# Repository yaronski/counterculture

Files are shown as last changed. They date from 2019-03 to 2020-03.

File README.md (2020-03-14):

# counterculture
Someone:
```
»Do you speak Chinese?«
```
You:
```
»No, but I can count to 10 in Chinese!«
```

Being able to quantify is essential while learning a new language. Also, it's cool.\
Combining visual and auditory sensory input at the push of an arcade style button, learning to count from 0 to 10 in Korean, Japanese, Chinese, Hindi, German and Polish is now easy and fun.

_counterculture_ is a device I invented & built to encourage starting to learn a new language and have some fun with electronics. A project realized during my stay at the National Taiwan University of Technology (NTUT) in Taipei.\
Digital Fabrication class by Prof. N. Tai, 2018/19.

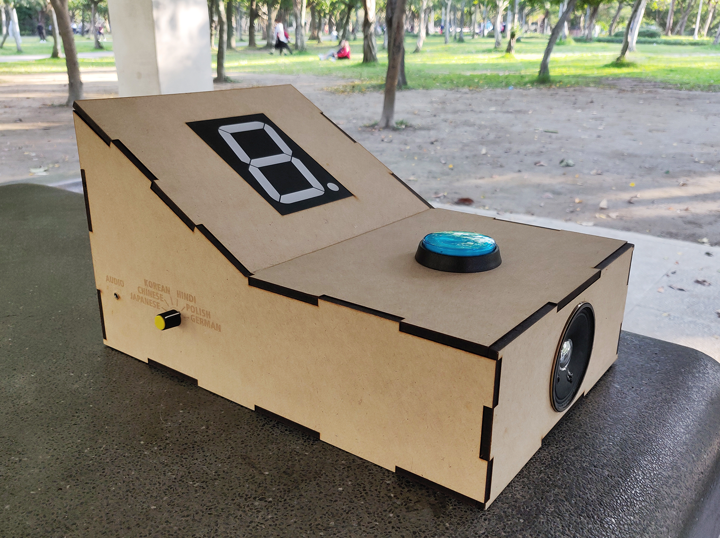
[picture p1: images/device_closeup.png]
device


### video
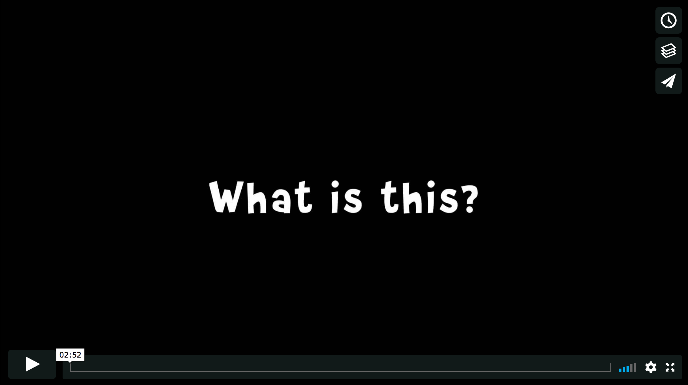
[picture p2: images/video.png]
counterculture (https://vimeo.com/322227320 "counterculture - click to watch!")


### highly complicated circuit diagram
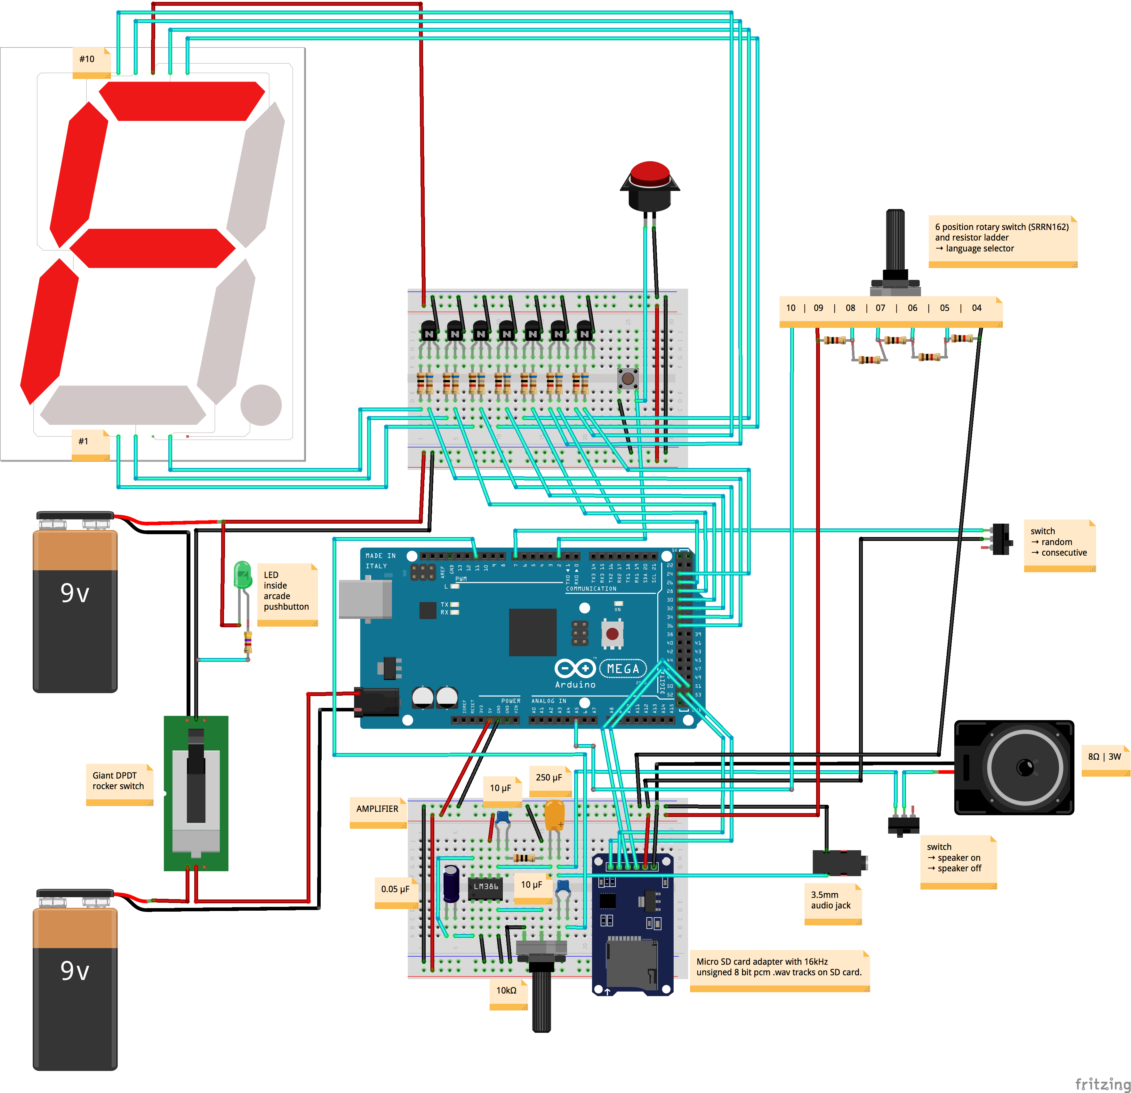
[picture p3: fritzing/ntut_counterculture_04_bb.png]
fritzing


### construction notes
- For lasercutting the box with teeth and slots, MDF sheets of 5mm thickness were used. Taking into account the kerf of the laser, the vector path's generated from Sketchup must be offset by around .19mm. However the exact value might vary depending on the speed used for cutting.
- Each audio file must be a in a 16000 Hz mono, unsigned 8-bit PCM WAV format to work with the [TMRpcm](https://github.com/TMRh20/TMRpcm/wiki) library. For me, this was the only format that worked perfectly fine.
- The circuit was built around an Arduino Mega board since I had one laying around and a very limited time-frame.\
However, a Teensy with built-in DAC or an Arduino MKR Zero with an I2S bus and compatibility with the [Arduino Sound library](https://www.arduino.cc/en/Reference/ArduinoSound) would make things simpler and be an improvement with regard to audio quality.\
Also, why not just use a [MAX08357 I2S Amp Breakout board](https://www.adafruit.com/product/3006) instead of building an amplifier circuit from scratch.
- While you're at it, add a repeat functionality for the most recent number played.
- Files in the _rdworks_ folder contain files for the laser cutter controlling software »RDWorks«. If you use a different software and a different laser cutter, the settings will vary most likely anyway. Text shapes are being engraved at high speed and low power, while the edges of the box are cut at low speed and high power. For the pieces to come off easily, it might help programming the laser to continue moving a tiny bit beyond the actual end of the line. 
- Adobe Illustrator artboards are in A3 size, since A3 sheets of 5mm MDF were used.
- The folder »audio« found inside the folder »sdcard« needs to be placed in the root directory of the FAT32 formatted SD card which is plugged in the slot of the SD card reader module.

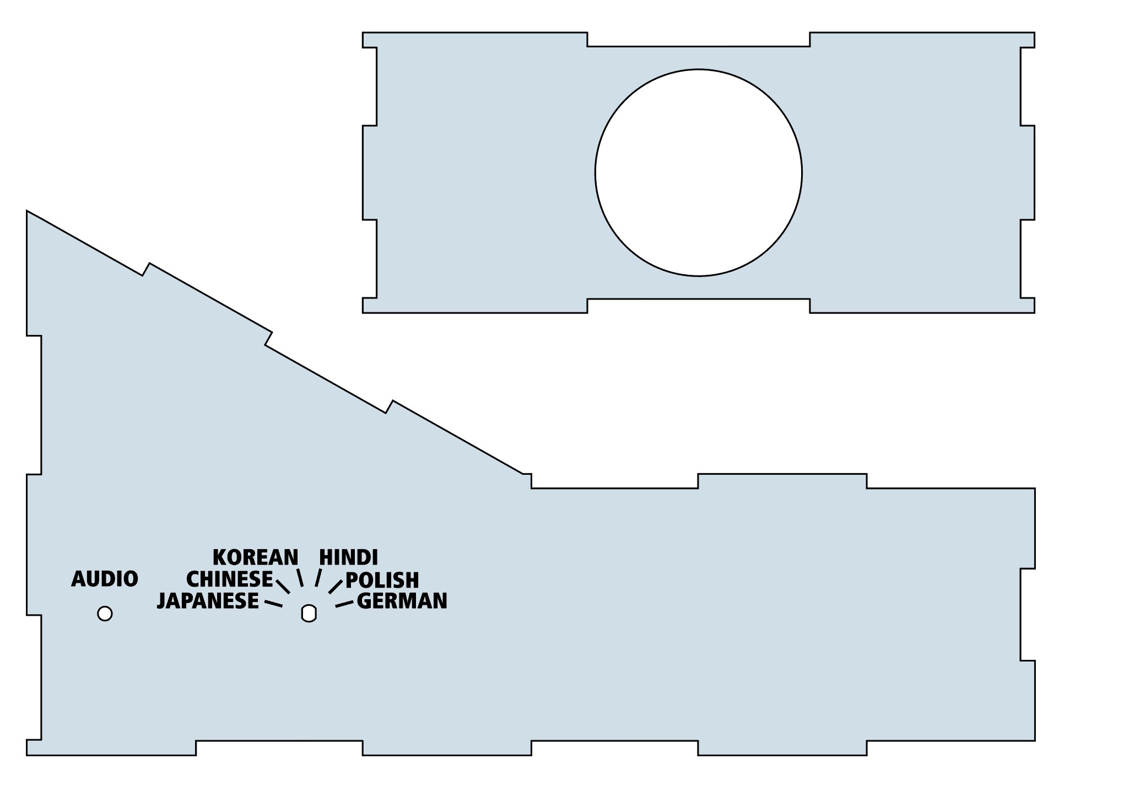
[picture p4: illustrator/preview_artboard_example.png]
ai


### quality control
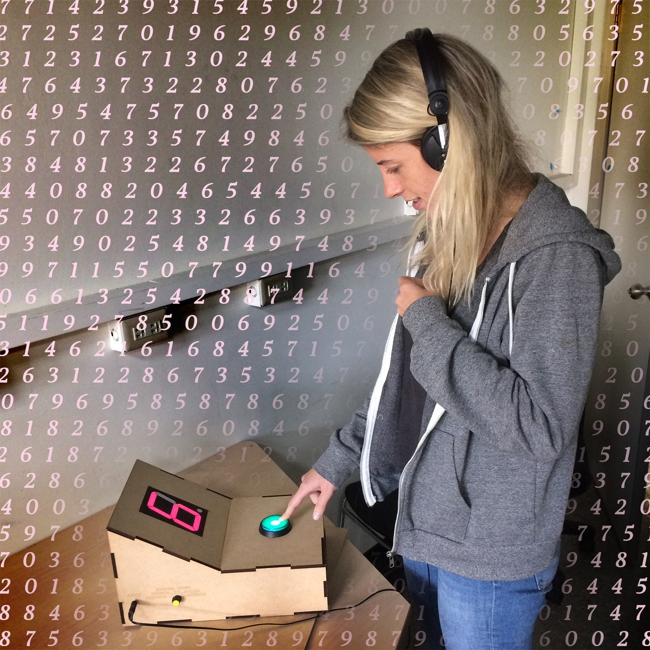
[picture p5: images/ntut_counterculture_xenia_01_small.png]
xenia Xenia


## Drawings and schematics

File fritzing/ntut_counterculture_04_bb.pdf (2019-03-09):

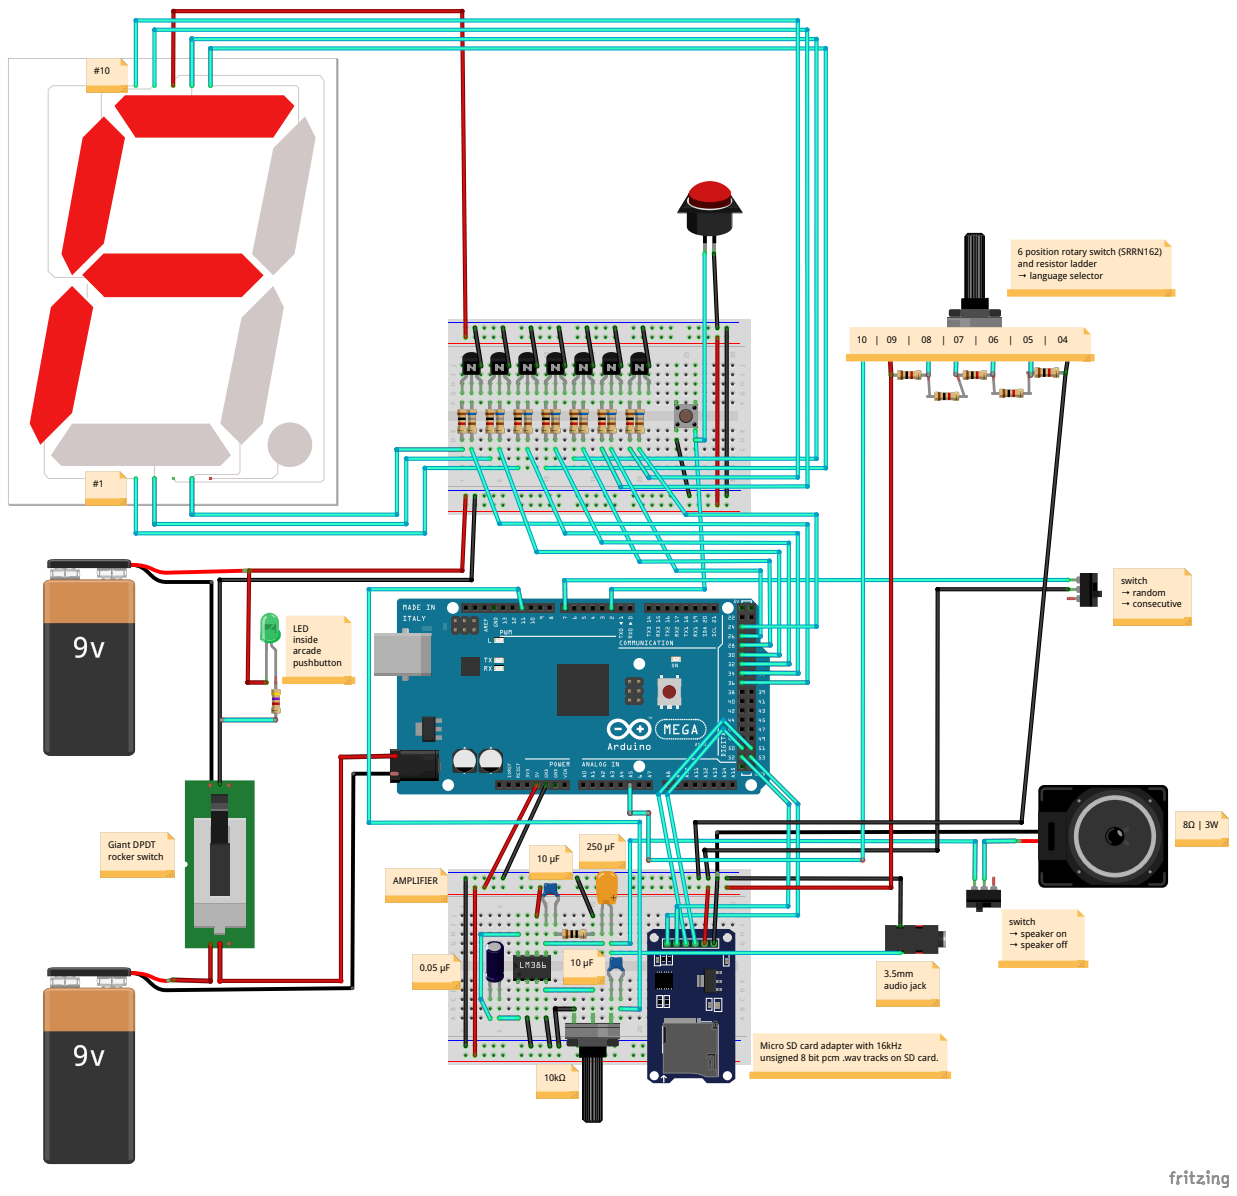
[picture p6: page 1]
Giant DPDT rocker switch; switch → random → consecutive; LED inside arcade pushbutton; switch → speaker on → speaker off; AMPLIFIER; 3.5mm audio jack

6 position rotary switch (SRRN162)
and resistor ladder
→ language selector

Micro SD card adapter with 16kHz
unsigned 8 bit pcm .wav tracks on SD card.

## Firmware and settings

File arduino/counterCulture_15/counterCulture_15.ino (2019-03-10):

/*
  ____Counter_Culture____
  → Learning to count ... 
  → easy as ichi, dwa, sān!
  
  Final Project
  Digital Fabrication by Prof. N.Tai
  NTUT 2018/19
  Y.Z.

*/

/**********************************/

#include "SD.h"                 //Lib to read SD card
#include "TMRpcm.h"             //Lib to play auido
#include "SPI.h"                //Lib SPI for SD card
#include "SevSeg.h"             //Lib 7 segment display

#define SD_ChipSelectPin 53     //Chip select is pin number 53 on Arduino Mega 2560
 
TMRpcm audio;                   //Lib object »audio«
SevSeg sevseg;                  //Lib object »sevseg«

/* languages: 
'jp' -> japanese
'cn' -> chinese
'ko' -> korean
'pl' -> polish
'hi' -> hindi
'de' -> german
*/

const String langArray[] = {"jp", "cn", "ko", "hi", "pl", "de"};
String lang;                                            

int song_number = -1;

int readSw = 0;
int maxVoltageBits = 1023;
float dividedBits = maxVoltageBits / 5;       // = 204,6 at 6 pos. rotary switch
int rotaryInput = A5;
int myDebounce = 150;
int randomButton = 7;
int rndVal = 0;
int mainButton = 2;

/*************************/
void setup() {

  audio.speakerPin = 11;
  int freshButtonpress = 1;

  // 7 segment disply
  byte numDigits = 1;
  byte digitPins[] = {};
  byte segmentPins[] = {28, 32, 36, 30, 34, 26, 24, 40};
  //28, 32, 36, 30, 34, 26, 24, 40         [Arduino pin]
  // A,  B,  C,  D,  E,  F,  G,  DP CHANGE [Display segment]
  // 7,  6,  4,  2,  1,  9, 10,  5         [Display pin]
  bool resistorsOnSegments = true;
  bool disableDecPoint = false;
  // 9V to the common pins (pin 8 & optionally pin 1) and ground to the segment pins
  byte hardwareConfig = COMMON_CATHODE;  
  
  sevseg.begin(hardwareConfig, numDigits, digitPins, segmentPins, resistorsOnSegments, disableDecPoint);

  Serial.begin(9600);
  if (!SD.begin(SD_ChipSelectPin)) {
    Serial.println("SD fail");
    return;
  }

  pinMode(mainButton, INPUT_PULLUP);      // Main button with internal pull-up to move to the next sound file
  pinMode(rotaryInput, INPUT);            // Analog in rotary switch

  pinMode(randomButton, INPUT_PULLUP);

  audio.setVolume(4);                     //  0 to 7. Set volume level
  audio.quality(0);                       //  Set 1 for 2x oversampling Set 0 for normal
}

/*************************/
void loop() {

  int freshButtonpress = 0;
  
  readSw = analogRead(rotaryInput) + 100;     // +100 to move away from the threshold of the adjacent language

  if (readSw < round(dividedBits * 1)) {
    lang = langArray[0];
  }
  else if (readSw < round(dividedBits * 2)) {
    lang = langArray[1];
  }
  else if (readSw < round(dividedBits * 3)) {
    lang = langArray[2];
  }
  else if (readSw < round(dividedBits * 4)) {
    lang = langArray[3];
  }
  else if (readSw < round(dividedBits * 5)) {
    lang = langArray[4];
  }
  else if (readSw > round(dividedBits * 5)) {
    lang = langArray[5];
  }

// **Debugging**
//  Serial.println(readSw);
//  Serial.println(lang);
//  Serial.print("song_number = ");
//  Serial.println(song_number);
//  Serial.print("Random Value = ");
//  Serial.println(rndVal);
//  Serial.print("freshButtonpress Before = ");
//  Serial.println(freshButtonpress);
//  Serial.println("/audio/" + lang + "_0" + String(song_number) + ".wav");

  if (digitalRead(mainButton) == LOW && rndVal == 0) {
    song_number++;
    Serial.println("Next button pressed");
    freshButtonpress = 1;
    delay(myDebounce);
  }

  if (digitalRead(mainButton) == LOW && rndVal == 1) {
    song_number = random(0, 11);
    freshButtonpress = 1;
    delay(myDebounce);
  }

  if (digitalRead(randomButton) == HIGH) {
    rndVal = 1;
    delay(10);
  }
  
  if (digitalRead(randomButton) == LOW && rndVal == 1){
    rndVal = 0;
    delay(10);
  }

  if (song_number == 11) {
    song_number = 0;
    delay(100);                 // avoid debounce
  }

  String path = "/audio/" + lang + "_0" + String(song_number) + ".wav";
  const char *newPath = path.c_str();
  
  if (freshButtonpress == 1){
    audio.play(newPath);
//    audio.loop(0); 
  }

  switch (song_number) {
    case -1:
      sevseg.blank();
      break;
    case 0:
      sevseg.setNumber(0, 0);
      break;
    case 1:
      sevseg.setNumber(1, 0);
      break;
    case 2:
      sevseg.setNumber(2, 0);
      break;
    case 3:
      sevseg.setNumber(3, 0);
      break;
    case 4:
      sevseg.setNumber(4, 0);
      break;
    case 5:
      sevseg.setNumber(5, 0);
      break;
    case 6:
      sevseg.setNumber(6, 0);
      break;
    case 7:
      sevseg.setNumber(7, 0);
      break;
    case 8:
      sevseg.setNumber(8, 0);
      break;
    case 9:
      sevseg.setNumber(9, 0);
      break;
    case 10:   

      int x = 0;

      if (x == 0){
        
      sevseg.blank();
      sevseg.refreshDisplay();
      
      digitalWrite(28, LOW);
      digitalWrite(32, LOW);
      digitalWrite(36, LOW);
      digitalWrite(30, LOW);
      digitalWrite(34, LOW);
      digitalWrite(26, LOW);
      digitalWrite(24, LOW);
            
      delay(200);

      digitalWrite(32, HIGH);
      digitalWrite(36, HIGH);
      
      delay(500);

      digitalWrite(28, HIGH);
      digitalWrite(32, HIGH);
      digitalWrite(36, HIGH);
      digitalWrite(30, HIGH);
      digitalWrite(34, HIGH);
      digitalWrite(26, HIGH);
      digitalWrite(24, LOW);

      delay(500);
      
      sevseg.blank();
      sevseg.refreshDisplay();
      
      x = 1;
      song_number = -1;      
      }
      break;      
  }

  sevseg.refreshDisplay();
  
  while (audio.isPlaying() == 1){
    delay(20);
  }

//  **Debugging**
//  Serial.print("freshButtonpress After = ");
//  Serial.println(freshButtonpress);

  if (freshButtonpress == 1 && audio.isPlaying() == 0) freshButtonpress == 0;
  delay(50);

//  **Debugging**
//  Serial.print("freshButtonpress End = ");
//  Serial.println(freshButtonpress);

}
